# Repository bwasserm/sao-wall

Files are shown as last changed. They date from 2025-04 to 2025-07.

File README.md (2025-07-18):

# SAO Wall

Mount your SAOs on your wall for display.

[Hackaday.io Page](https://hackaday.io/project/203082-sao-wall-tile)

## Design Goals
* Wall-mountable: that's the point
* USB-powered: Ubiquitous and easy to acquire
* Modular and Tileable: Easy to acquire arbitrary numbers to assemble and arrange however you want
* Chainable: Can be connected together to share a power source
* Simple: Can support SAOs that only require power without software
* Smart: Can support interacting with I2C and GPIO on smart SAOs
* Accessible: Keep component cost low and hand solderable for home assembly 

## Desgin trades/notes
* USB provides 5V 3A without a PD controller, which should be enough
* SAO [1.68bis](https://docs.google.com/document/u/0/d/1EJqvkkLMAPsQ9VWF5A4elWoi0qMlKyr5Giw5rqRmtnM/mobilebasic?pli=1) spec specifies 250mA max per SAO, but most are smaller, so a 500mA 3.3V regulator seems reasonable for 4 SAOs. However it can be easily swapped for another at lower or higher current.
* I tried board-edge connectors at first, but that really complicates making arbitrary layouts. Using cables makes that way easier, and USB-C connectors seem appropriate. Also, getting alignment correct of the connectors on the 60deg edges of the hexagon seemed more difficult.
* One in and two out connectors is enough to make a power binary tree. I don't have any current monitoring yet, so be careful how many boards and SAOs get connected to the same supply.
* 5cm per side is a nice round number, and keeps the tiles small, but big enough for the SAOs to have some space between them. Also, it should be plenty small enough for 0.3m USB cables between tiles, without being too tight or having too much extra slack to hide.
* The Raspberry Pi Pico W is optional, for talking to smart SAOs (I2C or GPIO) and controlling the 3.3V regulator to turn them on and off. A Pico 2 W should also work. I wanted this to be compatible with firmware similar to the 2024 Supercon badge.
* I picked Pico pins for 3 of the SAOs' GPIOs to be connected to UARTs on the Pico. It only has two UARTs, but at least those are options.
* I wanted to put a current shunt on the 3.3V regulator to measure the load of the SAOs, but I didn't want to have the voltage drop on that rail, or add the op-amp to measure the tiny voltage difference to do that properly. At least not on this rev, but maybe a future rev.
* No, its not going to be great RF performance from the Pico, but hopefully good enough.
* The tiles can be arranged or connected in any order. All smart behavior is localized to the one tile, so it doesn't matter where it gets connected in the chain.

## BOM
* 1x IC REG BUCK 3.3V 500MA TSOT23-5  MCP1603BT-330I/OS [Datasheet](https://ww1.microchip.com/downloads/aemDocuments/documents/OTH/ProductDocuments/DataSheets/22042B.pdf) [Digikey](https://www.digikey.com/en/products/detail/microchip-technology/MCP1603BT-330I-OS/22611630)
* 4x S9717-ND CONN HDR 6POS 0.1 GOLD PCB [Digikey](https://www.digikey.com/en/products/detail/sullins-connector-solutions/SFH11-NBPC-D03-ST-BK/4558818)
* 3x USB4125-GF-A CONN RCPT TYPE C 6P SMD RA [Datasheet](https://mm.digikey.com/Volume0/opasdata/d220001/medias/docus/6501/USB4125%20Product%20Spec.pdf) [Digikey](https://www.digikey.com/en/products/detail/gct/USB4125-GF-A/13547388)
* 2x 5.1k 0603 Resistor [Digikey](https://www.digikey.com/en/products/detail/yageo/RC0805JR-075K1L/728338)
* 2x 4.7uF+ Capacitor [Digikey](https://www.digikey.com/en/products/detail/samsung-electro-mechanics/CL21A106KOQNNNG/3894417)
* 1x 4.7uH Inductor [Digikey](https://www.digikey.com/en/products/detail/inpaq-technology-co-ltd/WIP252010S-4R7MLDG/20486610)
* 1x 1.4M Resistor [Digikey](https://www.digikey.com/en/products/detail/yageo/RC0805FR-071M4L/727488)

Digikey Shopping Cart: https://www.digikey.com/short/hjqzcd2n

Optional
* 1x Raspberry Pi Pico (2) W  [Pico W Datasheet](https://datasheets.raspberrypi.com/picow/pico-w-datasheet.pdf) [Pico 2 W Datasheet](https://datasheets.raspberrypi.com/picow/pico-2-w-datasheet.pdf)
* 2x 5.1k 0603 Resistors
* 1x Schottky 0603 Diode

# Renders
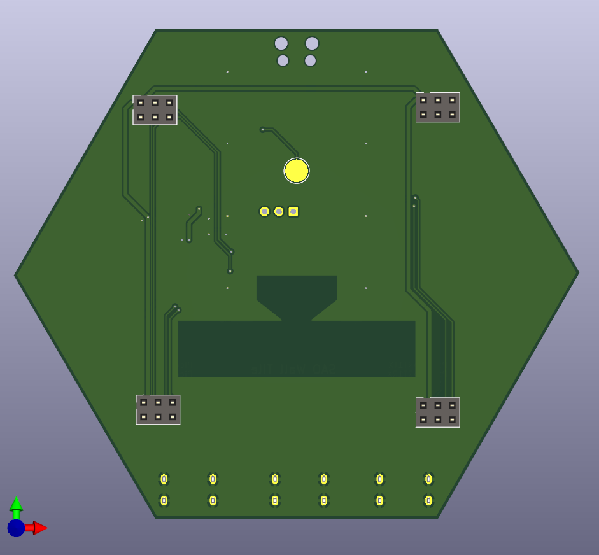
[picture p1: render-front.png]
Front Render

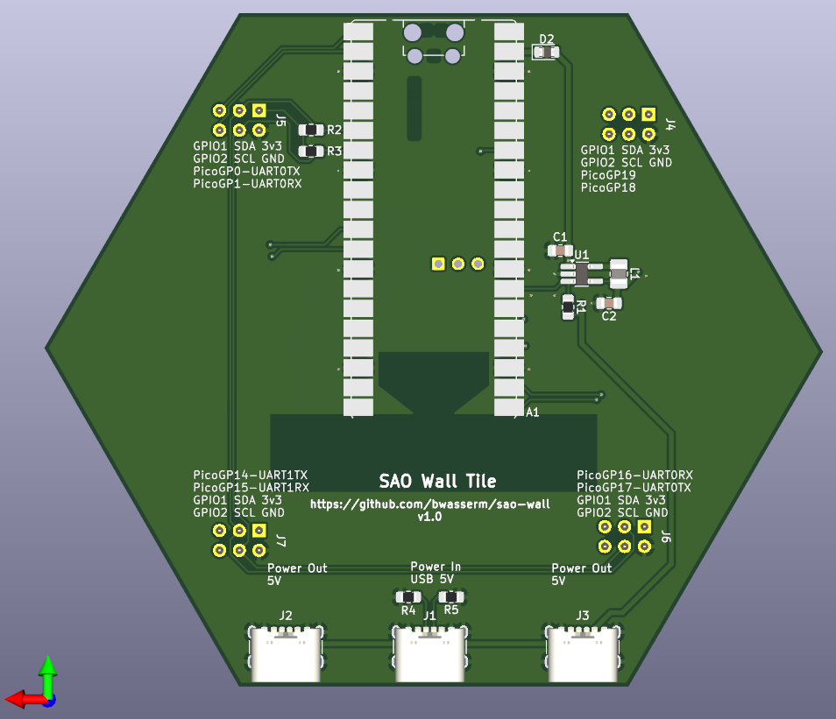
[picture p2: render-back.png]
Back Render


# Attribution and feedback
If you make and distribute this, please add a reference back to me or this repo so people can know where it came from. If you make any new designs to integrate into this system, please let me know so everyone can learn about them. Thanks!

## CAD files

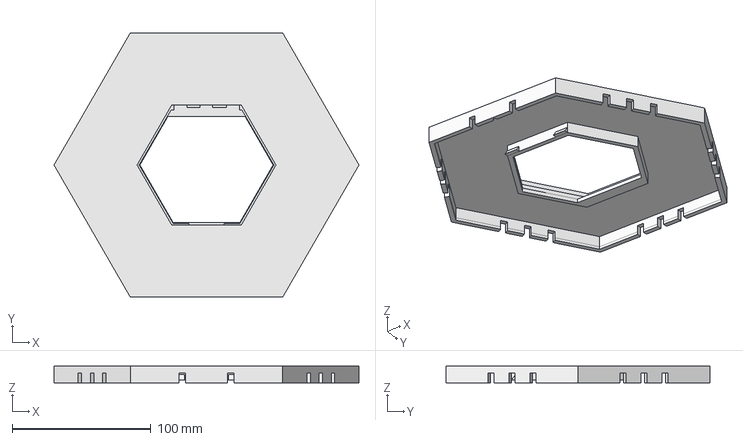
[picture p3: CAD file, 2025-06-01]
frame/sao-wall-frame.FCStd
220.0 x 190.5 x 12.0 mm

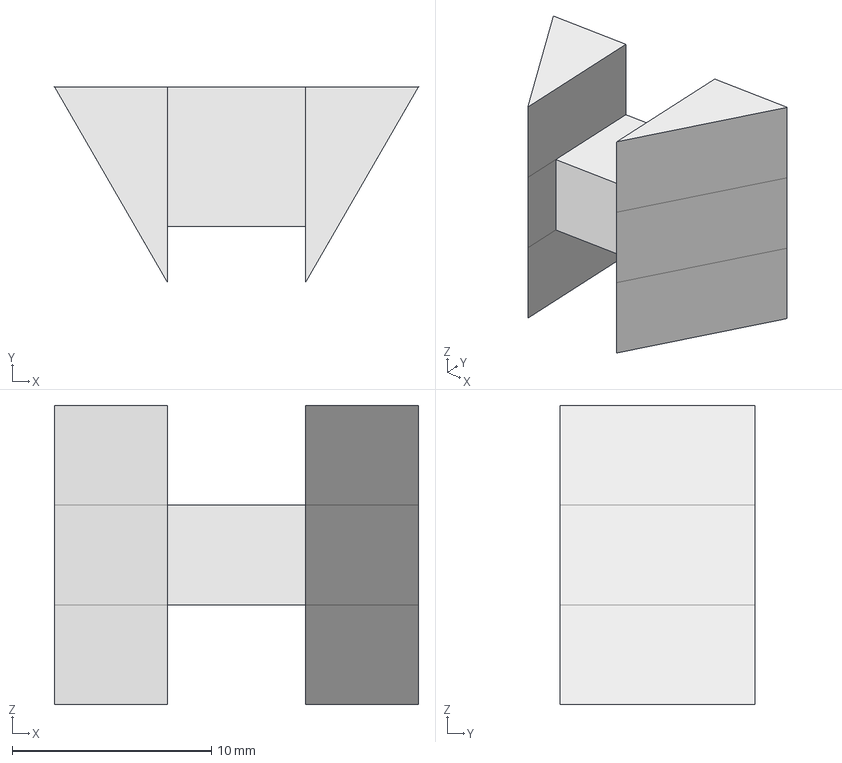
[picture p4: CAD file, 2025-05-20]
frame/frame-links.FCStd
18.3 x 9.80 x 15.0 mm

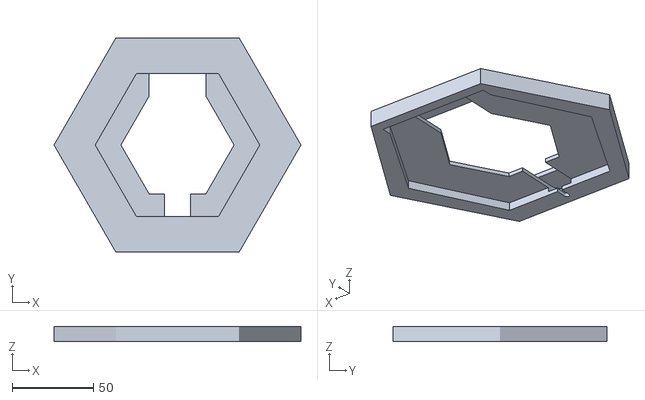
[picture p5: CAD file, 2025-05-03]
frame/sao-wall-frame-Body.stl
152.4 x 132.0 x 9.52

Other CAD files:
frame/sao-wall-tile-frame.stl
frame/clip.stl

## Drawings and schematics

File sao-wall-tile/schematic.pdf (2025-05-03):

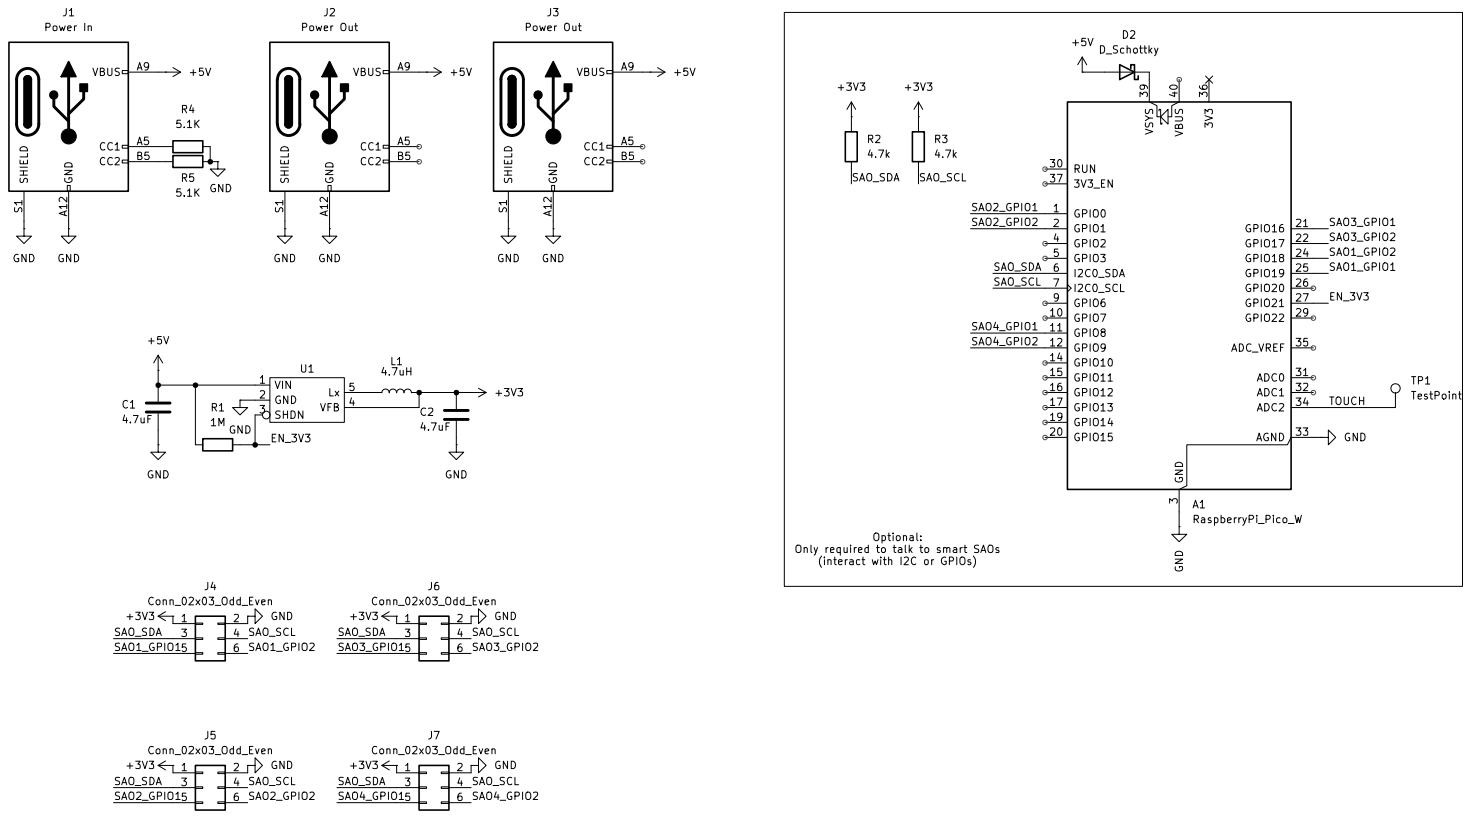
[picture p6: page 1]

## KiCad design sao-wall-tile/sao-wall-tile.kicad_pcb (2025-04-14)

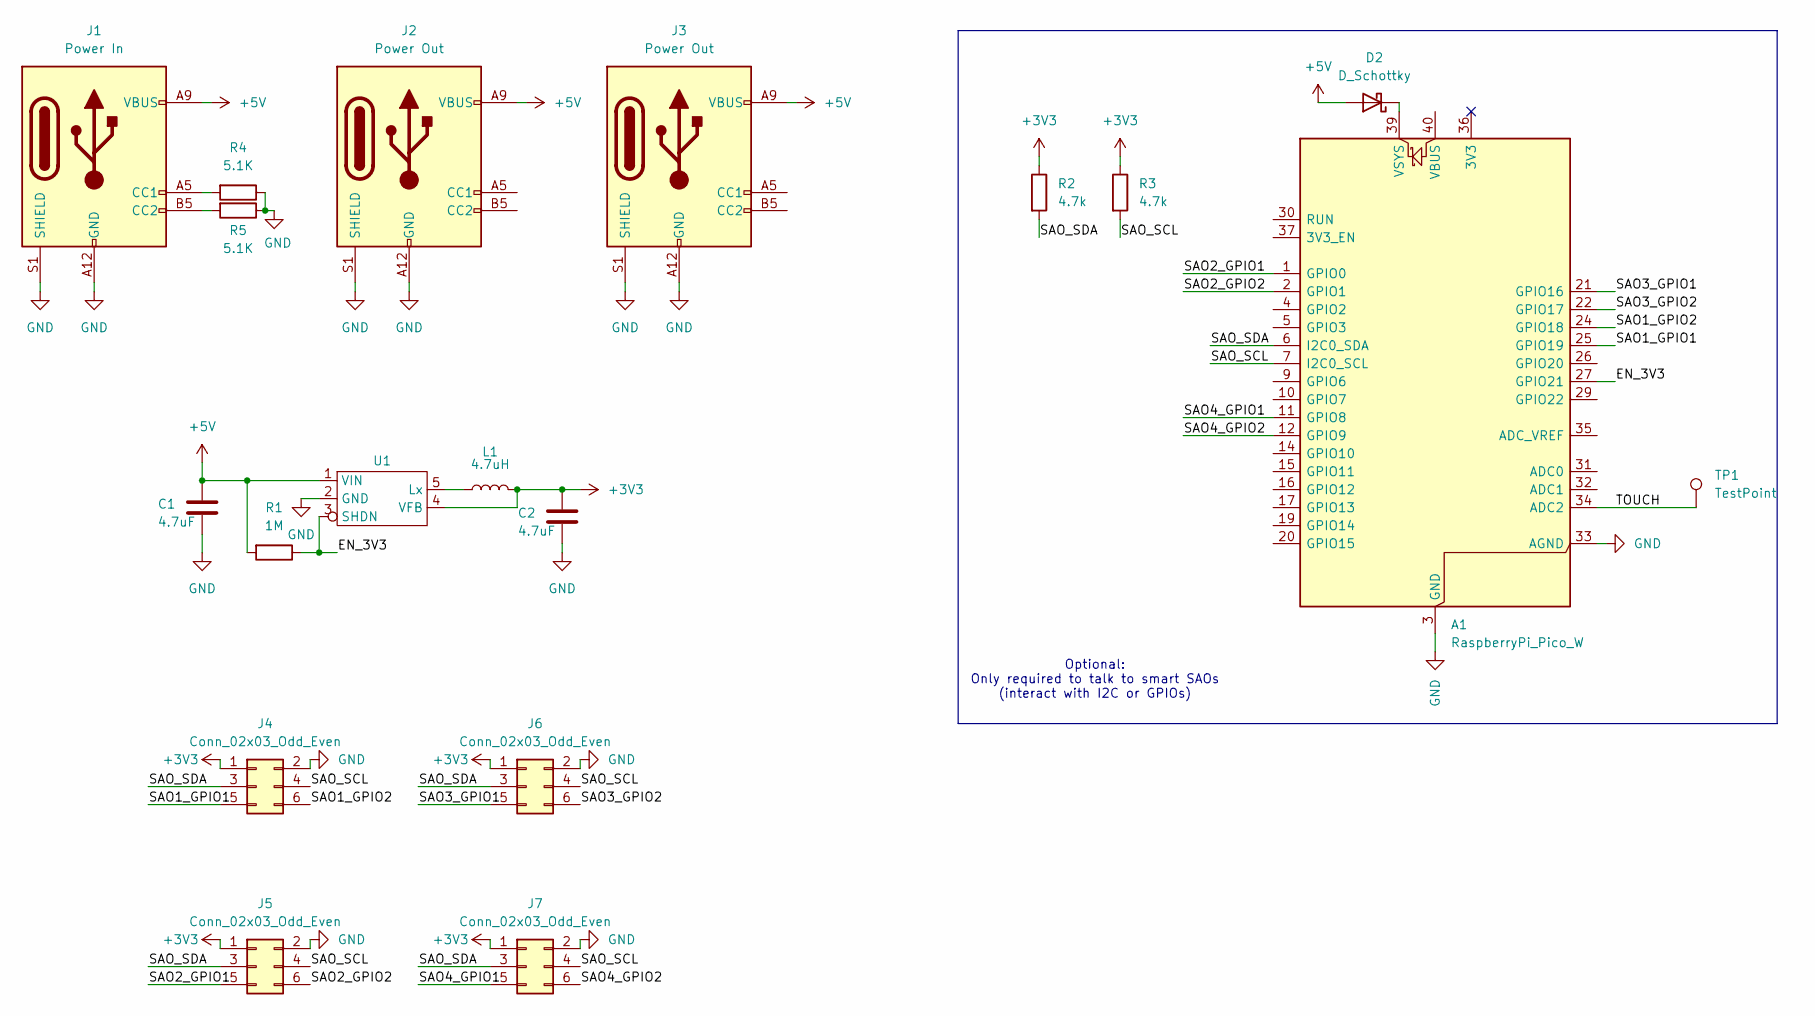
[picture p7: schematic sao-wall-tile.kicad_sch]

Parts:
A1: RaspberryPi_Pico_W; RaspberryPi_Pico_W_SMD_HandSolder
C1, C2: 4.7uF; C_0805_2012Metric_Pad1.18x1.45mm_HandSolder
D2: D_Schottky; D_0805_2012Metric_Pad1.15x1.40mm_HandSolder
J1: Power In; USB_C_Receptacle_GCT_USB4125-xx-x_6P_TopMnt_Horizontal
J2, J3: Power Out; USB_C_Receptacle_GCT_USB4125-xx-x_6P_TopMnt_Horizontal
J4, J5, J6, J7: Conn_02x03_Odd_Even; PinSocket_2x03_P2.54mm_Vertical
L1: 4.7uH; L_1008_2520Metric_Pad1.43x2.20mm_HandSolder
R1: 1M; R_0805_2012Metric_Pad1.20x1.40mm_HandSolder
R2, R3: 4.7k; R_0805_2012Metric_Pad1.20x1.40mm_HandSolder
R4, R5: 5.1K; R_0805_2012Metric_Pad1.20x1.40mm_HandSolder
TP1: TestPoint; TestPoint_Pad_D4.0mm
U1: TSOT-23-5_HandSoldering

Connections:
+3V3: C2.1, J4.1, J5.1, J6.1, J7.1, L1.2, R2.1, R3.1, U1.4 (VFB)
+5V: C1.1, D2.2 (A), J1.A9 (VBUS), J1.B9 (VBUS), J2.A9 (VBUS), J2.B9 (VBUS), J3.A9 (VBUS), J3.B9 (VBUS), R1.2, U1.1 (VIN)
/EN_3V3: A1.27 (GPIO21), R1.1, U1.3 (SHDN)
/SAO1_GPIO1: A1.25 (GPIO19), J4.5
/SAO1_GPIO2: A1.24 (GPIO18), J4.6
/SAO2_GPIO1: A1.1 (GPIO0), J5.5
/SAO2_GPIO2: A1.2 (GPIO1), J5.6
/SAO3_GPIO1: A1.21 (GPIO16), J6.5
/SAO3_GPIO2: A1.22 (GPIO17), J6.6
/SAO4_GPIO1: A1.11 (GPIO8), J7.5
/SAO4_GPIO2: A1.12 (GPIO9), J7.6
/SAO_SCL: A1.7 (I2C0_SCL), J4.4, J5.4, J6.4, J7.4, R3.2
/SAO_SDA: A1.6 (I2C0_SDA), J4.3, J5.3, J6.3, J7.3, R2.2
/TOUCH: A1.34 (ADC2), TP1.1
GND: A1.3 (GND), A1.8 (GND), A1.13 (GND), A1.18 (GND), A1.23 (GND), A1.28 (GND), A1.33 (AGND), A1.38 (GND), C1.2, C2.2, J1.A12 (GND), J1.B12 (GND), J1.S1 (SHIELD), J2.A12 (GND), J2.B12 (GND), J2.S1 (SHIELD), J3.A12 (GND), J3.B12 (GND), J3.S1 (SHIELD), J4.2, J5.2, J6.2, J7.2, R4.1, R5.1, U1.2 (GND)
unnamed: A1.39 (VSYS), D2.1 (K)
unnamed: J1.A5 (CC1), R4.2
unnamed: J1.B5 (CC2), R5.2
unnamed: L1.1, U1.5 (Lx)

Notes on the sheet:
Optional: Only required to talk to smart SAOs (interact with I2C or GPIOs)

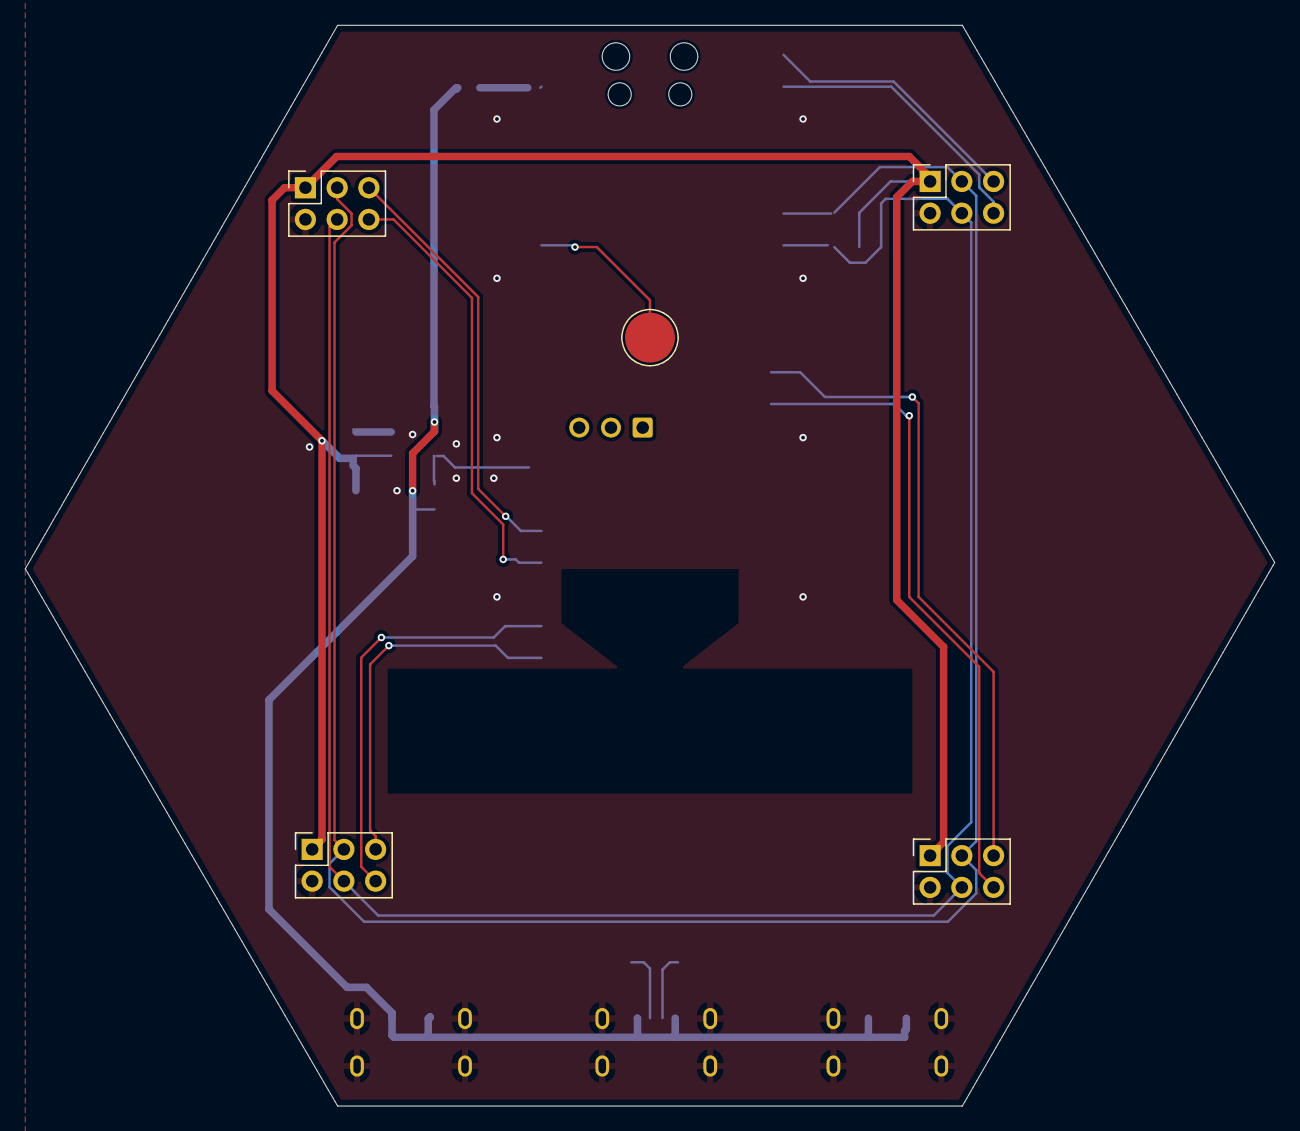
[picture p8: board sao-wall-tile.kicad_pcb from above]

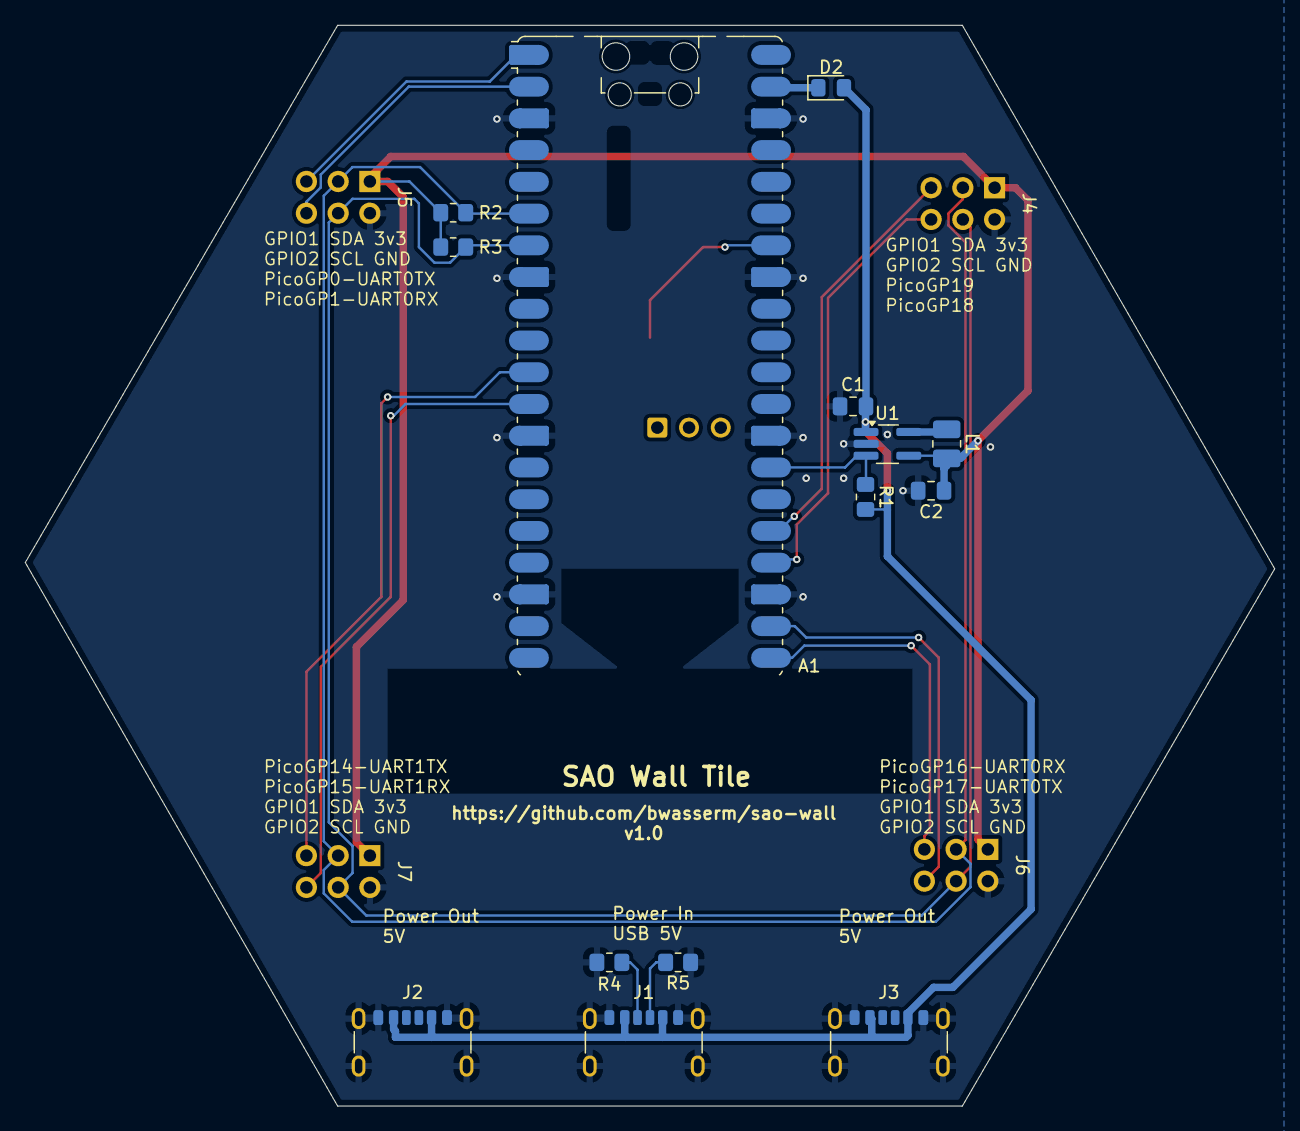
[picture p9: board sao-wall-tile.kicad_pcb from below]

Board: 2 copper layers, 100.0 x 86.5 mm, 19 parts (14 on the bottom side), 19 nets.

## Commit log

2024-11-08 Create sao wall tile first draft
    [sao-wall.kicad_pcb, sao-wall.kicad_sch]
2024-11-24 Make tile larger, still needs routing
    [sao-wall.kicad_pcb, sao-wall.kicad_sch]
2024-11-24 Routed traces
    [sao-wall.kicad_pcb]
2024-11-24 Small adjustments for pours
    [sao-wall.kicad_pcb]
2025-03-27 Add new wall tile design
    [sao-wall-tile.kicad_pcb, sao-wall-tile.kicad_sch]
2025-03-29 Remove old concept
    [sao-wall.kicad_pcb, sao-wall.kicad_sch]
2025-03-30 Add README, clean up schematic and layout
    [sao-wall-tile.kicad_pcb, sao-wall-tile.kicad_sch]
2025-04-13 Update from review feedback
    [sao-wall-tile.kicad_pcb, sao-wall-tile.kicad_sch]
2025-04-13 Updates from picking components on digikey
    [sao-wall-tile.kicad_pcb, sao-wall-tile.kicad_sch]
2025-04-13 Made C2 smaller
    [sao-wall-tile.kicad_pcb, sao-wall-tile.kicad_sch]
2025-04-14 Different buck converter for smaller and cheaper components
    [sao-wall-tile.kicad_pcb, sao-wall-tile.kicad_sch]
2025-04-14 Move GPIO pins, update from more review, enhance labels, update renders
    [sao-wall-tile.kicad_pcb, sao-wall-tile.kicad_sch]
2025-05-03 Exported schematic to pdf, saving frame before I remake it.
    [sao-wall-frame-Body.stl]
2025-05-04 Saving second rev
    [sao-wall-frame.FCStd]
2025-05-04 Rebuilt frame, slightly better
    [sao-wall-frame.FCStd]
2025-05-11 Larger and better, but need to go outer side back up to 110mm
    [sao-wall-frame.FCStd]
2025-05-17 Larger 110mm sides, seems like the right size. Need to add extra cable slots.
    [sao-wall-frame.FCStd]
2025-05-20 Add hackaday.io link to readme, add clip and frame stls
    [clip.stl, frame-links.FCStd, sao-wall-frame.FCStd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]
2025-06-01 Add cable hooks in frame
    [sao-wall-frame.FCStd, sao-wall-tile-frame.stl]
